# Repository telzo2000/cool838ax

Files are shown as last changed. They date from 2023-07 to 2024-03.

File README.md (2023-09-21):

# cool838ax / cool838axble

cool838ax / cool838axble is a small keyboard.
<br>
This keyboard has 38 keys.
<br>
cool838ax / cool838axble is an Alice layout.
<br>
cool838ax use RP2040-Zero,run QMK_firmware.
<br>
cool838axble use Ble Micro Pro,run QMK_Firmware,and Bluetooth。

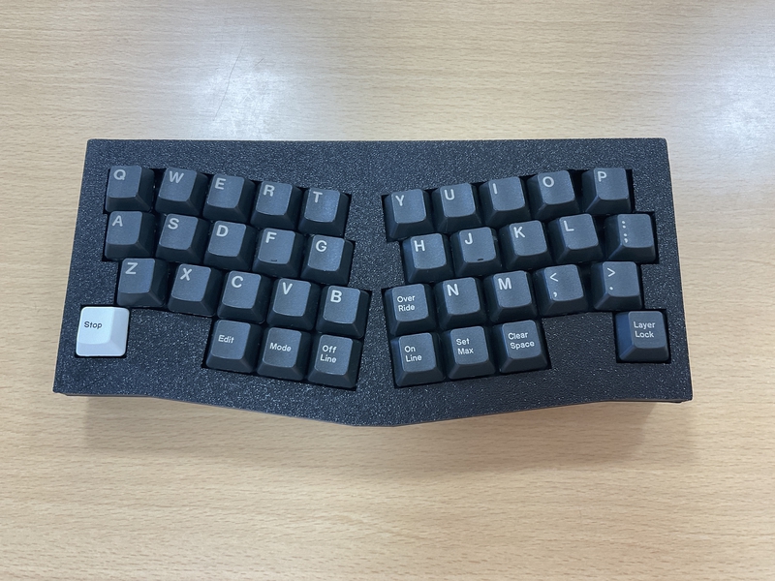
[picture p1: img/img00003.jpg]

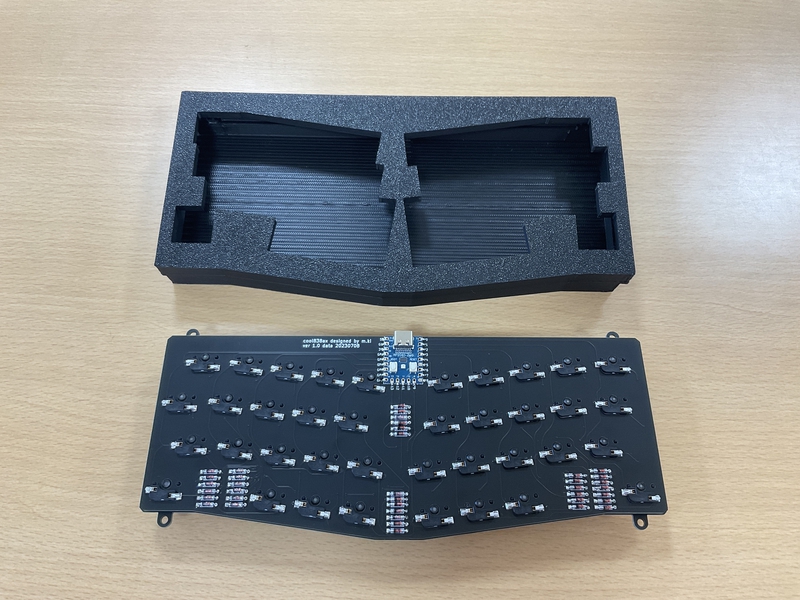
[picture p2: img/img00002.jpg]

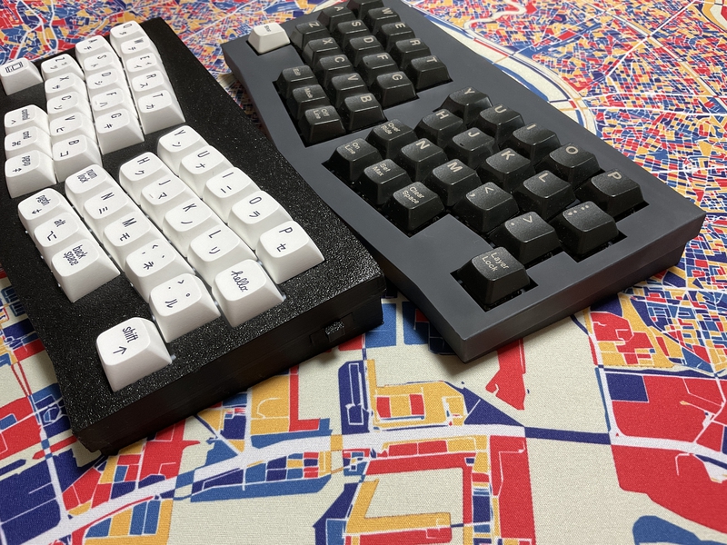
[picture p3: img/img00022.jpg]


## Firmware

[Here](https://github.com/telzo2000/cool838ax/tree/main/firmware)

## Buildguide

For cool838ax
<br>
https://github.com/telzo2000/cool838ax/blob/main/buildguide_for_cool838ax.md
<br>
For cool838axble
<br>
https://github.com/telzo2000/cool838ax/blob/main/buildguide_for_cool838axble.md
### Builde log

[Tweet](https://twitter.com/0002ozlet/status/1682569430923087872?s=20)

## Parts list

### For cool838ax

| No. | Patrs | Quantity | remarks | Suppliers | Cost |
|--|--|--|--|--|--|
|番号|名前|数|備考|調達先|参考価格（送料込）|<br>
|1|PCB|1|38key AlicLayout|[elecrow](https://www.elecrow.com)<br>[JLCPCB](https://jlcpcb.com)<br>[ALLPCB](https://www.allpcb.com)|５枚で20〜30ドル|<br>
|2|Switch Plate|1||[elecrow](https://www.elecrow.com)<br>[JLCPCB](https://jlcpcb.com)<br>[ALLPCB](https://www.allpcb.com)|５枚で20〜30ドル|<br>
|3|RP-2040Zero|1||[Talp Keyboard](https://talpkeyboard.net)|800円|
|4|Swith socket<br>スイッチソケット|38|cherry MX互換|[遊舎工房](https://yushakobo.jp)<br>[Talp Keyboard](https://talpkeyboard.net)<br>[Daily Craft Keyboard](https://shop.dailycraft.jp)等|10個で165円程度|
|5|Diode<br>ダイオード|38|リードタイプでもSMDでも可|[遊舎工房](https://yushakobo.jp)<br>[Talp Keyboard](https://talpkeyboard.net)<br>[Daily Craft Keyboard](https://shop.dailycraft.jp)等|100個で220円程度から|
|6|TopCase|1|3D Print|||
|7|BottomCase|1|3D Print||

### For cool838axble

| No. | Patrs | Quantity | remarks | Suppliers | Cost |
|--|--|--|--|--|--|
|番号|名前|数|備考|調達先|参考価格（送料込）|<br>
|1|PCB|1|38key AlicLayout|[elecrow](https://www.elecrow.com)<br>[JLCPCB](https://jlcpcb.com)<br>[ALLPCB](https://www.allpcb.com)|５枚で20〜30ドル|<br>
|2|Switch Plate|1||[elecrow](https://www.elecrow.com)<br>[JLCPCB](https://jlcpcb.com)<br>[ALLPCB](https://www.allpcb.com)|５枚で20〜30ドル|<br>
|3|Ble Micro Pro|1|12or13ピンコンスルーも必要|[遊舎工房](https://shop.yushakobo.jp/products/ble-micro-pro?_pos=1&_sid=192f46387&_ss=r)|4950円|
|4|Swith socket<br>スイッチソケット|38|cherry MX互換|[遊舎工房](https://yushakobo.jp)<br>[Talp Keyboard](https://talpkeyboard.net)<br>[Daily Craft Keyboard](https://shop.dailycraft.jp)等|10個で165円程度|
|5|Diode<br>ダイオード|38|リードタイプでもSMDでも可|[遊舎工房](https://yushakobo.jp)<br>[Talp Keyboard](https://talpkeyboard.net)<br>[Daily Craft Keyboard](https://shop.dailycraft.jp)等|100個で220円程度から|
|6|TopCase|1|3D Print|||
|7|BottomCase|1|3D Print||
|8|Switch Parts|1|3D Print||
|9|コンデンサー|1||[秋月電子](https://akizukidenshi.com/catalog/g/gP-02151/)|10個200円|
|10|スライドスイッチ|1||[遊舎工房](https://shop.yushakobo.jp/products/5624?variant=45044666007783)|110円|
|11|リセット用タクトスイッチ|1|なくても大丈夫|[Talp Keyboards](https://talpkeyboard.net/items/5fa258a5f0b10814d183347f)<br>[遊舎工房](https://shop.yushakobo.jp/products/a0800ts-01-1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)|1個11〜22円|
|12|電池ボックス|1|CR1632電池１個も必要|[モノタロウ](https://www.monotaro.com/p/8835/2765/)|１個239円|

In addition, you will need a USB cable, keycaps, etc.
<br>
この他に、USBケーブル、キーキャップ等が必要です。
<br>

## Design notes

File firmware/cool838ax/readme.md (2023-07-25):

# cool838ax

cool838ax

*A short description of the keyboard/project*

* Keyboard Maintainer: [m.ki](https://github.com/telzo2000)
* Hardware Supported: *The PCBs, controllers supported*
* Hardware Availability: *Links to where you can find this hardware*

Make example for this keyboard (after setting up your build environment):

    make cool838ax:default

Flashing example for this keyboard:

    make cool838ax:default:flash

See the [build environment setup](https://docs.qmk.fm/#/getting_started_build_tools) and the [make instructions](https://docs.qmk.fm/#/getting_started_make_guide) for more information. Brand new to QMK? Start with our [Complete Newbs Guide](https://docs.qmk.fm/#/newbs).

## Bootloader

Enter the bootloader in 3 ways:

* **Bootmagic reset**: Hold down the key at (0,0) in the matrix (usually the top left key or Escape) and plug in the keyboard
* **Physical reset button**: Briefly press the button on the back of the PCB - some may have pads you must short instead
* **Keycode in layout**: Press the key mapped to `QK_BOOT` if it is available

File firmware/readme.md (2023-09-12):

# Firmware

Support QMK_Firmware.
<br>
QMK_Firmwareに対応。
<br>
<br>
Compatible with [Remap](https://remap-keys.app/catalog/pLXvG6i1dYtpbWD7ujzv) and [VIA](https://usevia.app/).
<br>
[Remap](https://remap-keys.app/catalog/pLXvG6i1dYtpbWD7ujzv)と[VIA](https://usevia.app/)に対応。
<br>
File name: cool838ax_via.uf2
<br>
<br>
Compatible with [VIAL](https://get.vial.today/).
<br>
[VIAL](https://get.vial.today/)に対応。
<br>
File name: cool838ax_vial.uf2
<br>
20230912　The version of qmk_Firmware now corresponds to 0.22.

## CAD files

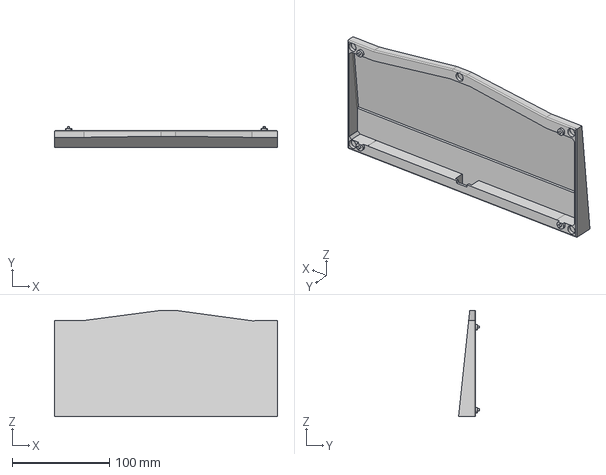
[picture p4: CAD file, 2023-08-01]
case_design/step_cool838ax/cool838ax_casedesign_bottom v14.step
229.0 x 21.5 x 109.2 mm

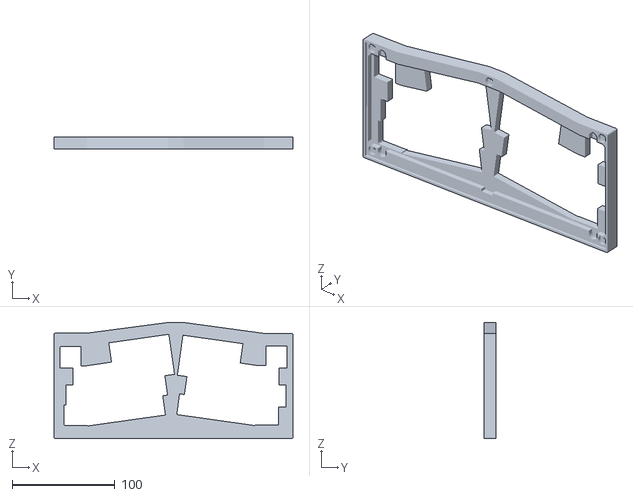
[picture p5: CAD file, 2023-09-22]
case_design/stl_cool838axble/cool838axl_casedesign_top v7.stl
233.0 x 12.0 x 113.2

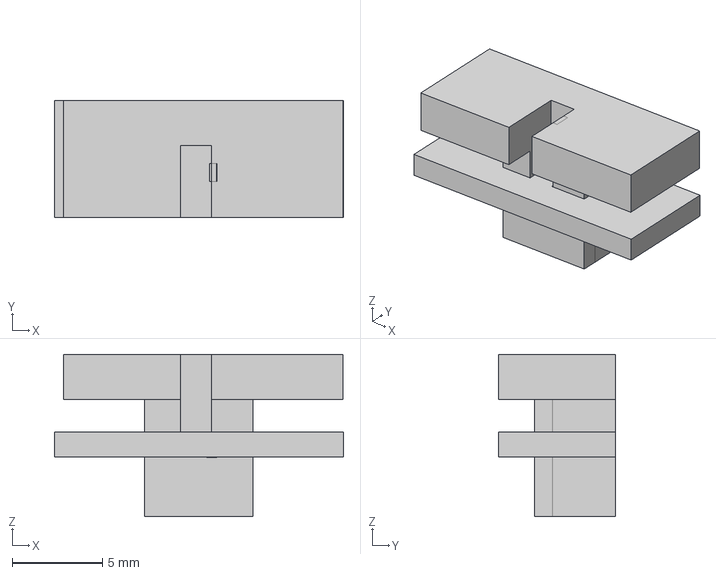
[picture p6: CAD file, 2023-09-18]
case_design/step_cool838axble/switch_knob v10.step
16.0 x 6.50 x 9.00 mm

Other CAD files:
case_design/step_cool838axble/cool838axble_bottom v3.step
case_design/stl_cool838ax/cool838ax_casedesign_bottom v13.stl
case_design/step_cool838ax/cool838axl_casedesign_top v6.step
case_design/step_cool838axble/cool838axl_casedesign_top v6.step
case_design/stl_cool838ax/cool838axl_casedesign_top v6.stl
case_design/stl_cool838axble/cool838axble_bottom v3.stl
case_design/stl_cool838axble/switch_knob v10.stl

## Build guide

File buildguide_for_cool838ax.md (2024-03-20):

## Build guide

## Firmware

###  QMK_FIRMWARE

参考<br>

https://github.com/telzo2000/Hello_keyboard/blob/main/readme_about_firmware.md

[Here](https://github.com/telzo2000/cool838ax/tree/main/firmware)

<br>

[remap](https://remap-keys.app/catalog/pLXvG6i1dYtpbWD7ujzv)

<br>

## Build 1

### 1 Diode soldering

Solder the diodes to the back of PCB.
<br>
PCBの裏面にダイオードのハンダ付けをします。
<br>
There are lead type and SMD diodes.
<br>
ダイオードはリードタイプか、SMDがあります。
<br>
Here, we will explain the lead type soldering.
<br>
ここでは、リードタイプのハンダ付けの説明をします。
<br>

Use a lead bender to bend the legs of the diode.
<br>
リードベンダーを使い、ダイオードの足を曲げます。
<br>
Insert the diode into the board.
<br>
ダイオードを基板に挿しこみます。
<br>

Please pay attention to the orientation of the diode.
<br>
ダイオードの向きに注意してください。
<br>

Secure the diode with masking tape, then face up.
<br>
マスキングテープでダイオードを固定してから、表面を上にします。
<br>
Solder the protruding legs.
<br>
はみ出ている足部分に、ハンダ付けをします。
<br>
After soldering, use nippers to cut off the protruding legs.
<br>
はんだ付けが終わったら、はみ出ている足をニッパーで切り取ってください。
<br>

[８倍速　Diodeハンダ付け動画](https://youtu.be/Yaodh2-XxV4)

<br>
<br>

### 2 Soldering switch sockets

Solder the switch sockets on the back side.
<br>
裏面にスイッチソケットのハンダ付けをします。
<br>

[８倍速　Switch socketハンダ付け動画](https://youtu.be/E__mHvmIXQo)

<br><br>

### 3　Soldering RP-2040Zero  

The side on which the RP-2040Zero components are mounted is the front side, and the opposite side is the back side.
<br>
RP-2040Zeroの部品実装されている面を表面とし、反対側を裏面とします。
<br>
Place the back side of the PCB and the back side of the RP-2040Zero facing each other and solder the respective terminals.
<br>
PCBの裏面とRP-2040Zeroの裏面が向かい合うようにして置き、それぞれの端子をハンダ付けします。
<br>
<br>

### 4 Instorlling QMK＿Firmware

Install QMK_Firmware from your PC to RP-2040Zero.
<br>
QMK_FirmwareをPCからRP-2040Zeroにインストールしてください。
<br>
<br>
① Download https://github.com/telzo2000/cool838ax/blob/main/firmware/cool838ax_via.uf2　to your PC.
<br>
①https://github.com/telzo2000/cool838ax/blob/main/firmware/cool838ax_via.uf2　をPCにダウンロードしておく。

<br><br>
② Connect the PC and RP-2040Zero with a USB cable.
<br>
②PCとRP-2040ZeroをUSBケーブルで繋ぐ。
<br><br>
③Press the reset button while pressing the boost button on the RP-2040Zero.
<br>
③RP-2040Zeroのboostボタン押しながら、resetボタンを押す。
<br><br>
④Since there is a folder of RP-2040Zero on the PC screen, drag and drop the downloaded cool838ax.uf2 there.
<br>
④PC画面にはRP-2040Zeroのフォルダがあるので、そこに、ダウンロードしたcool838ax.uf2をドラッグアンドドロップする。
<br><br>

⑤Check if it is recognized by connecting to remap. Edit the keymap accordingly.
<br>
⑤remapに繋いで認識するかどうか確認する。合わせてキーマップの編集をする。

### Build 2(case)

### 1 Case

I will explain using a case printed by stereolithography of black resin ordered from JLCPCB. The procedure is basically the same for cases printed with Ankemake M5 for home use.
<br>
JLCPCBに発注したブラックレジンの光造形で印刷されたケースを使って説明します。家庭用AnkemakeM5で印刷したケースでも作業の手順は、基本的に同じです。
<br>
<br>
Fix the magnets to the five dents inside the case with an adhesive or the like. There are ５ in the top case and ５ in the bottom case for a total of １０.Please pay attention to the polarity of the magnet. Make sure the top case and bottom case are magnetically attached.
<br>
ケースの内側にある５つの凹みに磁石を接着剤などで固定します。トップケースに５箇所、ボトムケースに５箇所の合計１０箇所です。
極性に注意してください。トップケースとボトムケースが磁力で着くようにしてください。
<br>
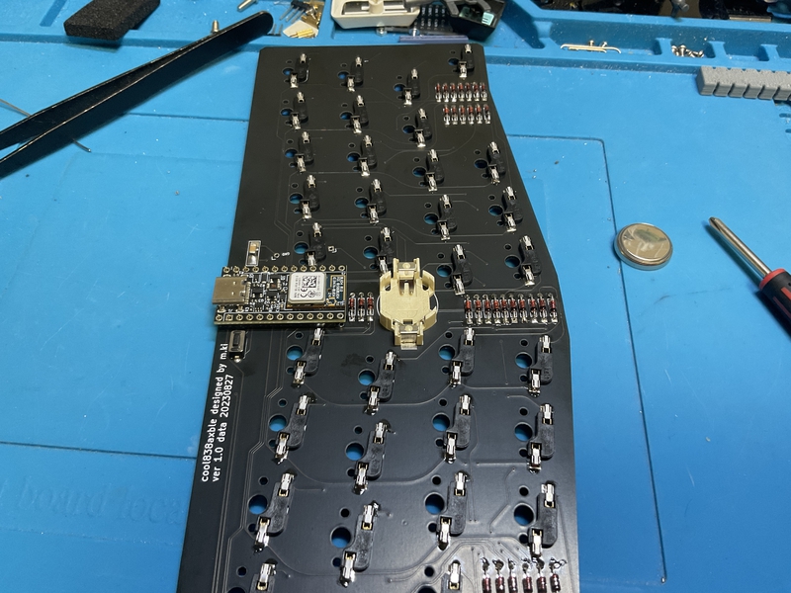
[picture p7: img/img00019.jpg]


As shown in the image below, attach rubber O-rings to the four protrusions on the bottom case. This makes it a gasket mount. You can do without the O-ring, but the PCB may move up and down inside the case.
<br>
下の画像のように、ボトムケースに4箇所の凸部にゴムのO-ringを装着します。これによりガスケットマウントとなります。O-ringはなくても大丈夫ですが、ケース内で、PCBが上下に動く可能性があります。
<br>
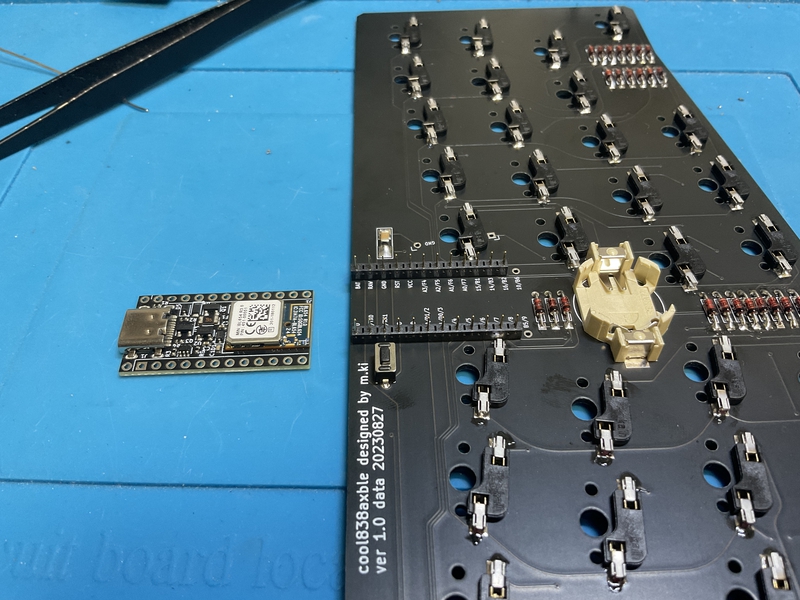
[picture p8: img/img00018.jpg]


The O-ring in the image is [this product](https://www.amazon.co.jp/gp/product/B07G4SM5SM/ref=ppx_yo_dt_b_asin_title_o03_s00?ie=UTF8&psc=1).
<br>
画像のO-ringは[この商品](https://www.amazon.co.jp/gp/product/B07G4SM5SM/ref=ppx_yo_dt_b_asin_title_o03_s00?ie=UTF8&psc=1)です。
<br>
<br>
Place the hole in the switch plate on the O-ring. And it is completed by covering the top case.
<br>
スイッチプレートの穴をO-ringに載せます。そして、トップケースを被せて完成です。
<br>

Welcome to the world of 38 keys.
<br>
38キーの世界へようこそ。
<br>


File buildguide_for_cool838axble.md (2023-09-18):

## Build guide

## Firmware

###  QMK_FIRMWARE

[Here](https://github.com/telzo2000/cool838ax/tree/main/firmware)

<br>

[remap](https://remap-keys.app/catalog/pLXvG6i1dYtpbWD7ujzv)

<br>

## Build 1

### 1 Diode soldering

Solder the diodes to the back of PCB.
<br>
PCBの裏面にダイオードのハンダ付けをします。
<br>
There are lead type and SMD diodes.
<br>
ダイオードはリードタイプか、SMDがあります。
<br>
Here, we will explain the lead type soldering.
<br>
ここでは、リードタイプのハンダ付けの説明をします。
<br>

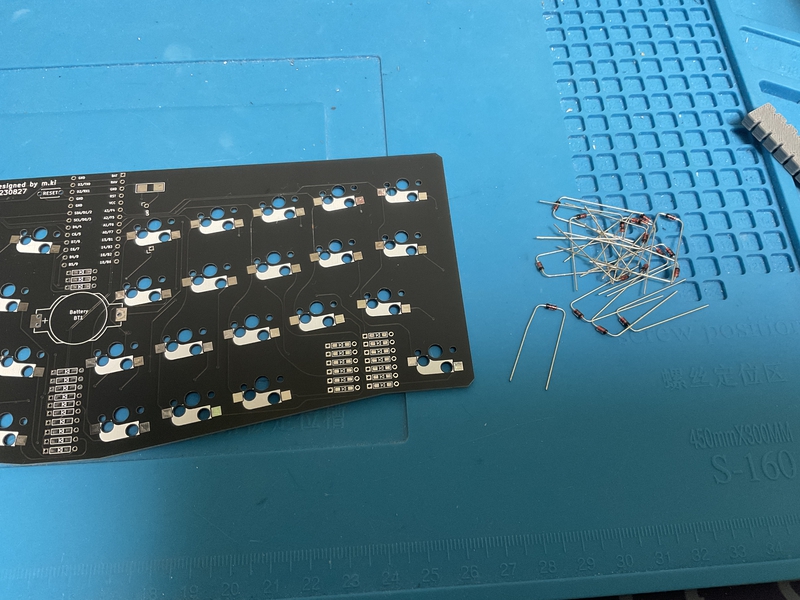
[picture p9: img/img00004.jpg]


Use a lead bender to bend the legs of the diode.
<br>
リードベンダーを使い、ダイオードの足を曲げます。
<br>
Insert the diode into the board.
<br>
ダイオードを基板に挿しこみます。
<br>

Please pay attention to the orientation of the diode.
<br>
ダイオードの向きに注意してください。
<br>

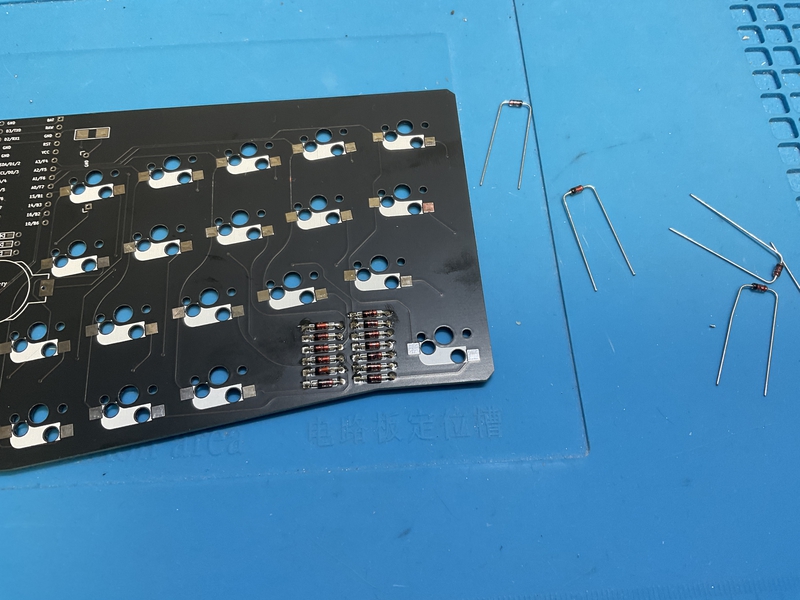
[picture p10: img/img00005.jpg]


Secure the diode with masking tape, then face up.
<br>
マスキングテープでダイオードを固定してから、表面を上にします。
<br>
Solder the protruding legs.
<br>
はみ出ている足部分に、ハンダ付けをします。
<br>
After soldering, use nippers to cut off the protruding legs.
<br>
はんだ付けが終わったら、はみ出ている足をニッパーで切り取ってください。
<br>

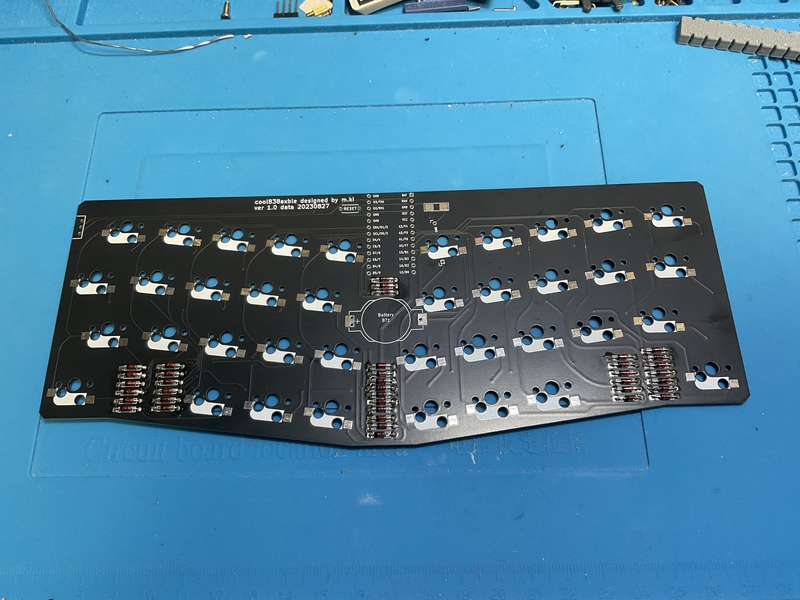
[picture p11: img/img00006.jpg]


[８倍速　Diodeハンダ付け動画](https://youtu.be/Yaodh2-XxV4)

<br>
<br>

### 2 Soldering switch sockets

Solder the switch sockets on the back side.
<br>
裏面にスイッチソケットのハンダ付けをします。
<br>

[８倍速　Switch socketハンダ付け動画](https://youtu.be/E__mHvmIXQo)

<br><br>

### 3 Soldering the capacitor

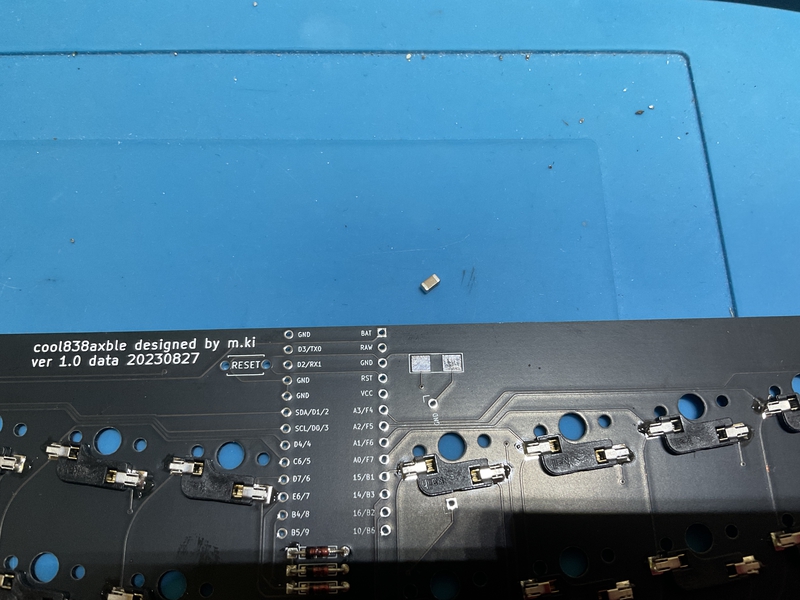
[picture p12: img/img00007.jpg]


Solder the [capacitor](https://akizukidenshi.com/catalog/g/gP-02151/).
<br>
[コンデンサー](https://akizukidenshi.com/catalog/g/gP-02151/)をハンダ付けします。
<br>

First, apply solder to the terminal on one side. Then, place the capacitor, melt the solder, and fix it.
<br>
最初に、片側の端子にハンダを盛ります。そして、コンデサーを置き、ハンダを溶かして、固定します。
<br>

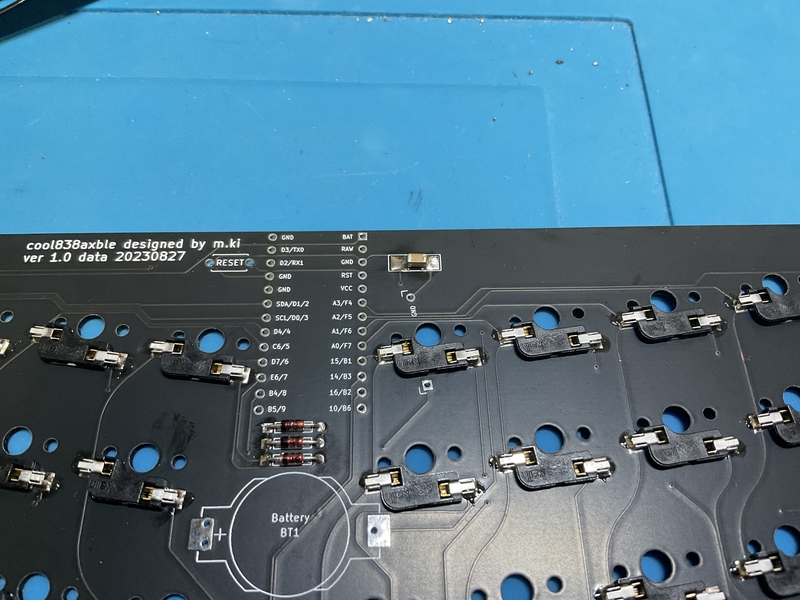
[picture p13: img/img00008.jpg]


Next, melt and pour solder into the other terminal and attach the capacitor. Please fix it.
<br>
次に、もう片側の端子にハンダを溶かして、流し込んで、コンデンサーを。固定してください。
<br>
<br>

### 4 Soldering the slide switch

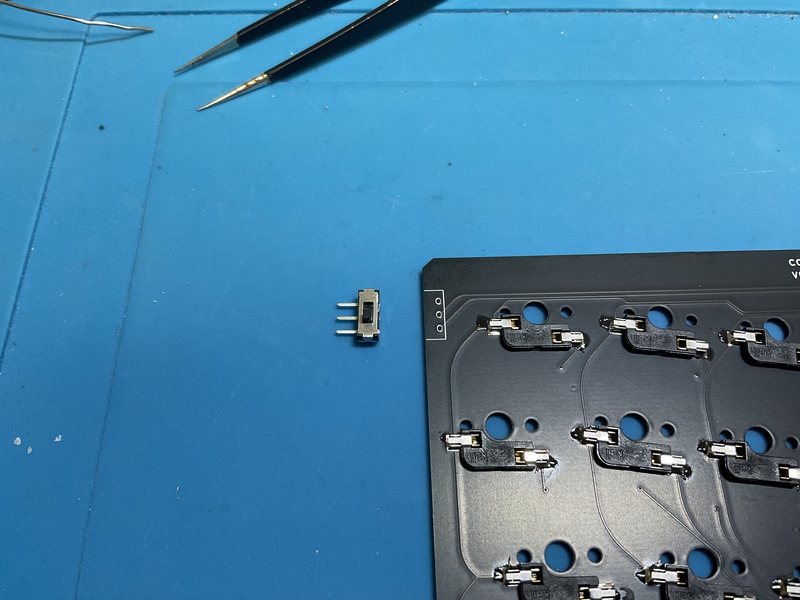
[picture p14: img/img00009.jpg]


Insert the [slide switch](https://shop.yushakobo.jp/products/5624?variant=45044666007783) from the back side of the PCB and solder the front side. Please remove the protruding legs.
<br>
[スライドスイッチ](https://shop.yushakobo.jp/products/5624?variant=45044666007783)はPCBの裏面から挿入して、表面をハンダ付けします。はみ出た足は、切り取ってください。
<br>

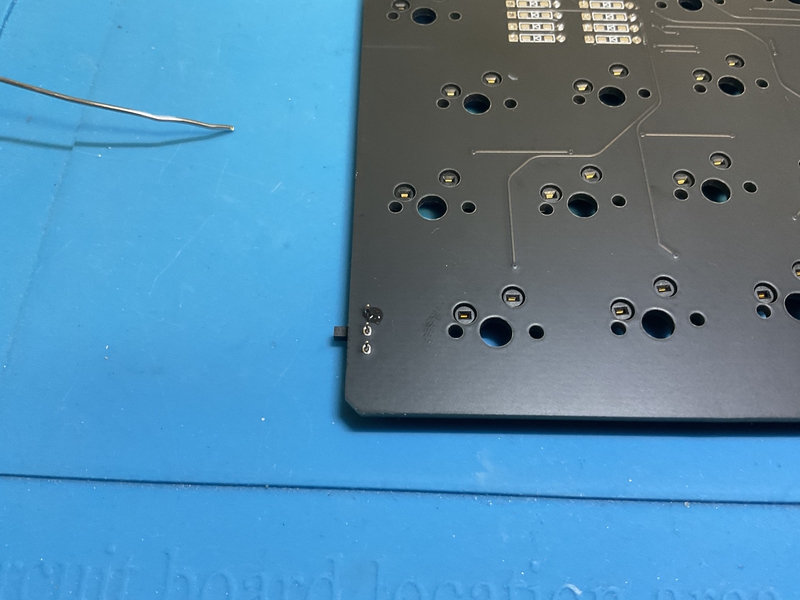
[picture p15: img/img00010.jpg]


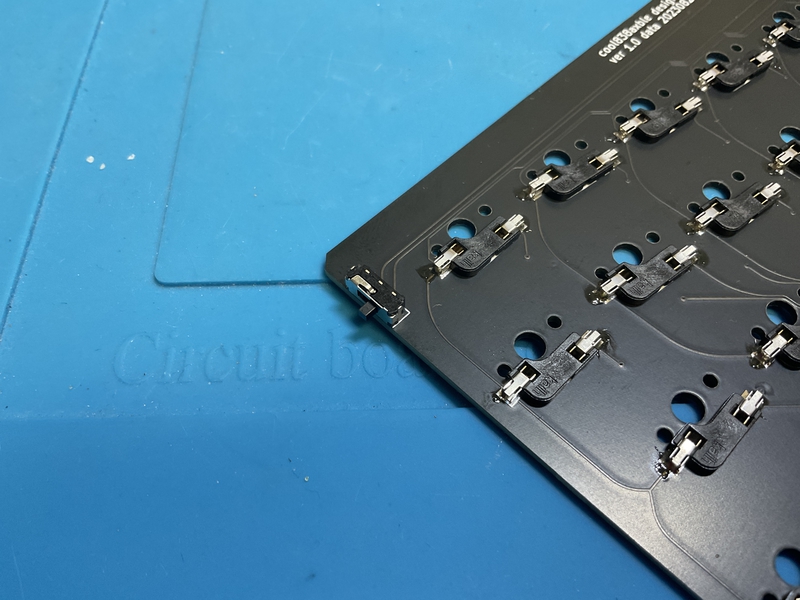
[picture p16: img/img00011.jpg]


### 5 Soldering the battery case

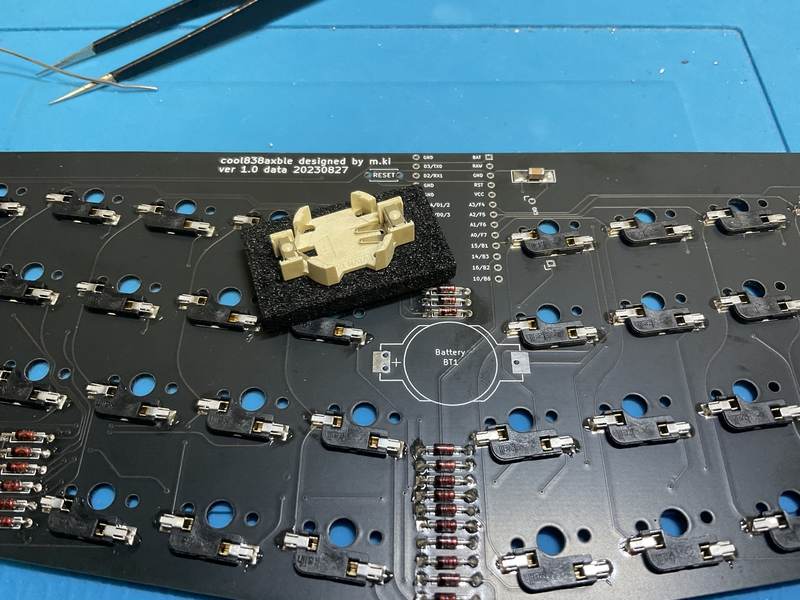
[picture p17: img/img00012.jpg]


[Battery box](https://www.monotaro.com/p/8835/2765/) is inserted from the back of the PCB and soldered on the front side. The protruding legs. Please cut it out.
<br>
[電池ボックス](https://www.monotaro.com/p/8835/2765/)は、PCB裏面から挿入して、表面をハンダ付けします。はみ出た足は。切り取ってください。

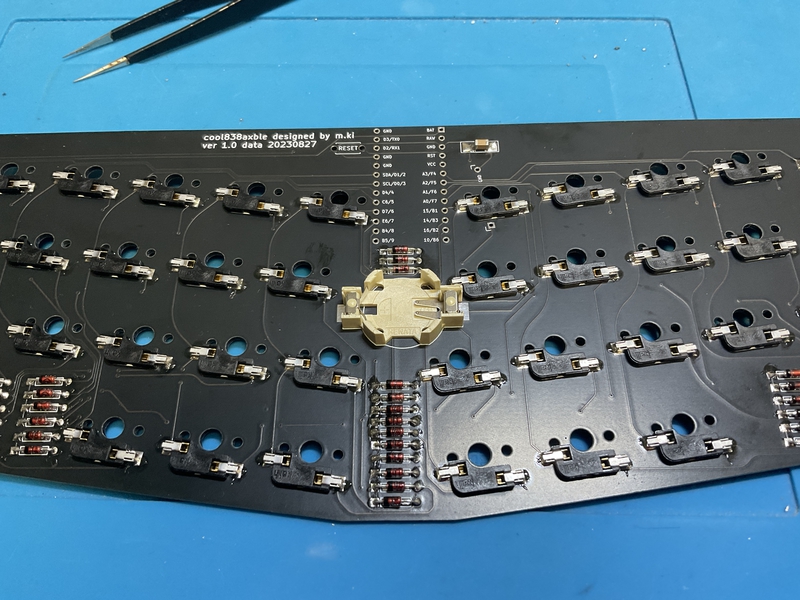
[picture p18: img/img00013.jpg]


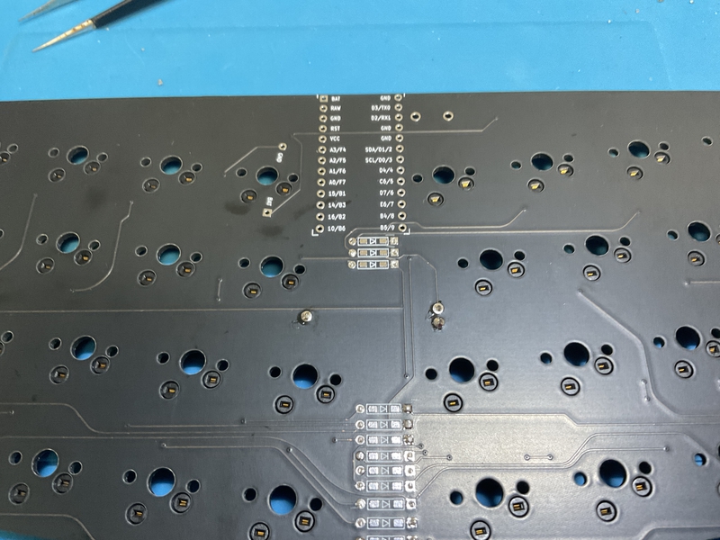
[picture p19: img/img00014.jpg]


### 6 (Option) Solering the reset switch

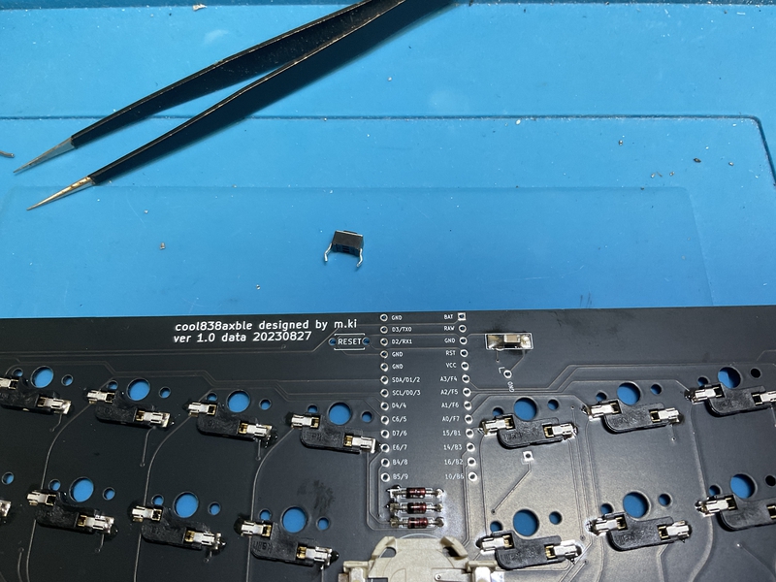
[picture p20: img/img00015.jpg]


Actually, it's not necessary. If you are an ncool838axble and are trying to install a WPRO microw without buying a Ble Micro Pro, you will need a reset switch.
<br>

実は必要ありません。もし、あなたがncool838axbleなのに、Ble Micro Proをおごることをせずに、ただのpro micro取り付けようとするならば、リセットスイッチは必要でしょうね。
<br>

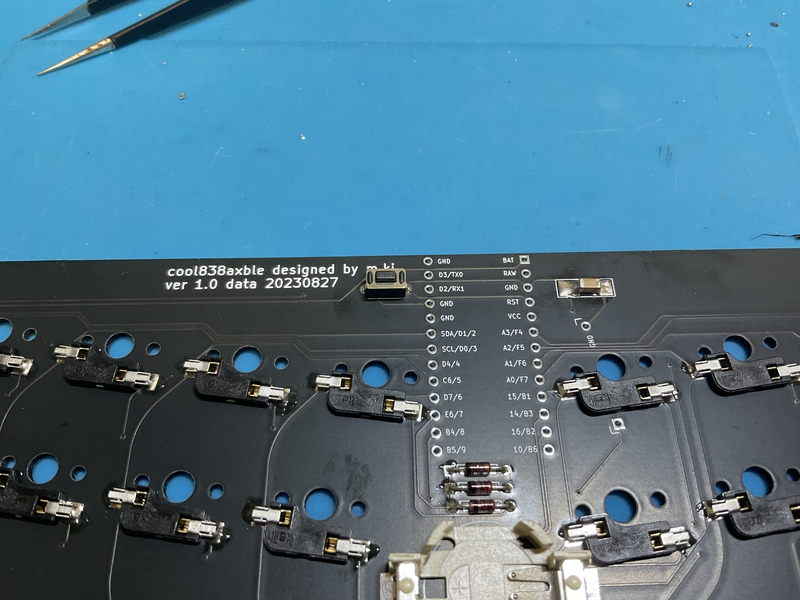
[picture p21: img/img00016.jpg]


### 7 Ble Micro Pro

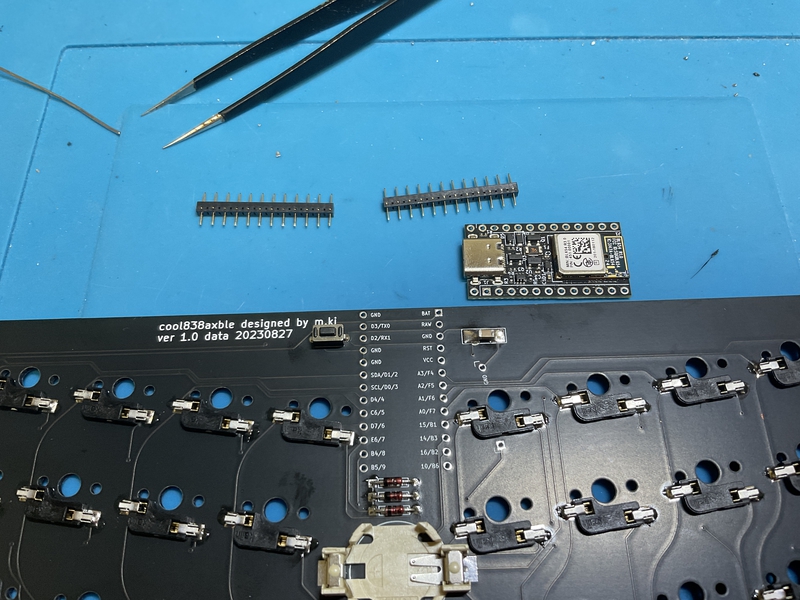
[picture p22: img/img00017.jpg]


Please prepare [Ble Micor Pro](https://shop.yushakobo.jp/products/ble-micro-pro?_pos=1&_sid=192f46387&_ss=r).
<br>
[Ble Micor Pro](https://shop.yushakobo.jp/products/ble-micro-pro?_pos=1&_sid=192f46387&_ss=r)を用意してください。
<br>

If it is a 12-pin con-through, install it as shown in the image. Then insert the Ble Micro Pro.

12ピンコンスルーであれば、画像のように、取り付けてください。そして、Ble Micro Proを挿入してください。
<br>





### 8 Please insert the batteries.

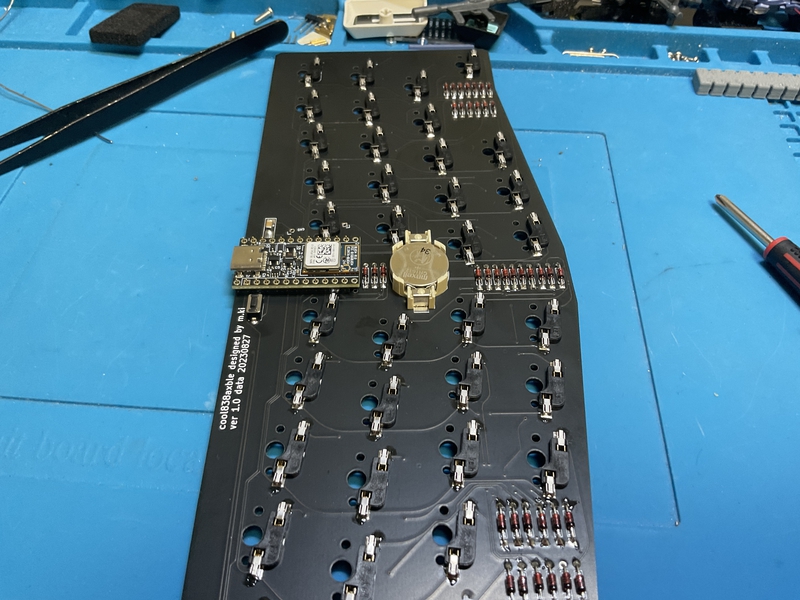
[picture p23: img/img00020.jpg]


Insert the CR1632 battery into the battery box.
<br>
CR1632電池を電池ボックスに挿入してください。
<br>
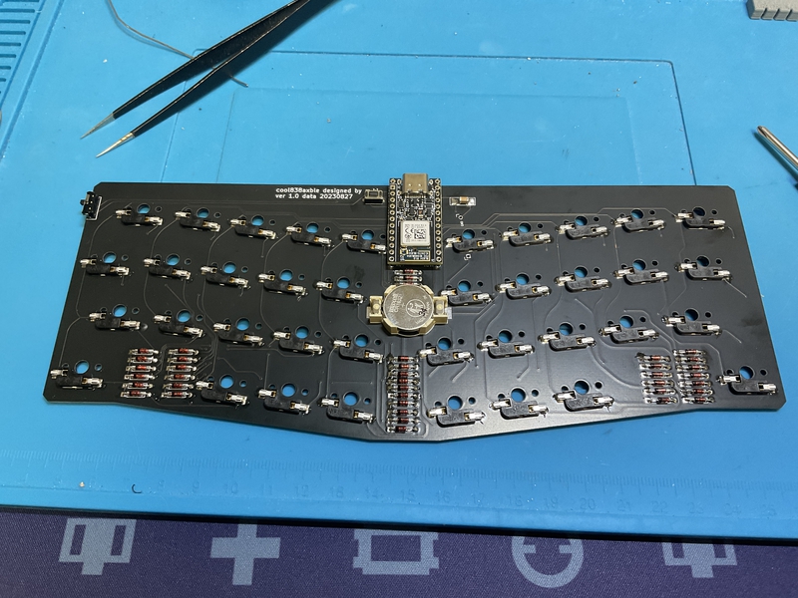
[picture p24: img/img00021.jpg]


### 9 Firmware

"6 Installing QMK_Firmware on Ble Micro pro" from [this site](https://github.com/telzo2000/cool836qalble/blob/main/build_guide_cool836qalble.md). please refer.
<br>
[このサイト](https://github.com/telzo2000/cool836qalble/blob/main/build_guide_cool836qalble.md)の「6 Instorlling QMK＿Firmware on Ble Micro pro」を。参考にしてください。
<br>

### Build 2(case)

### 1 Case

I will explain using a case printed by stereolithography of black resin ordered from JLCPCB. The procedure is basically the same for cases printed with Ankemake M5 for home use.
<br>
JLCPCBに発注したブラックレジンの光造形で印刷されたケースを使って説明します。家庭用AnkemakeM5で印刷したケースでも作業の手順は、基本的に同じです。
<br>
<br>
Fix the magnets to the five dents inside the case with an adhesive or the like. There are ５ in the top case and ５ in the bottom case for a total of １０.Please pay attention to the polarity of the magnet. Make sure the top case and bottom case are magnetically attached.
<br>
ケースの内側にある５つの凹みに磁石を接着剤などで固定します。トップケースに５箇所、ボトムケースに５箇所の合計１０箇所です。
極性に注意してください。トップケースとボトムケースが磁力で着くようにしてください。
<br>

As shown in the image below, attach rubber O-rings to the four protrusions on the bottom case. This makes it a gasket mount. You can do without the O-ring, but the PCB may move up and down inside the case.
<br>
下の画像のように、ボトムケースに4箇所の凸部にゴムのO-ringを装着します。これによりガスケットマウントとなります。O-ringはなくても大丈夫ですが、ケース内で、PCBが上下に動く可能性があります。
<br>

The O-ring in the image is [this product](https://www.amazon.co.jp/gp/product/B07G4SM5SM/ref=ppx_yo_dt_b_asin_title_o03_s00?ie=UTF8&psc=1).
<br>
画像のO-ringは[この商品](https://www.amazon.co.jp/gp/product/B07G4SM5SM/ref=ppx_yo_dt_b_asin_title_o03_s00?ie=UTF8&psc=1)です。
<br>
Pay attention to the orientation of the Switch Parts and attach them to the bottom case.
<br>
Switch Partsの向きに注意して、ボトムケースに取り付けてください。
<br>

<br>
Place the hole in the switch plate on the O-ring. And it is completed by covering the top case.
<br>
スイッチプレートの穴をO-ringに載せます。このとき、水平スライドスイッチのつまみがSwitch Pasrtsの窪みに入るようにしてください。そして、トップケースを被せて完成です。
<br>

Welcome to the world of 38 keys.
<br>
38キーの世界へようこそ。
<br>
